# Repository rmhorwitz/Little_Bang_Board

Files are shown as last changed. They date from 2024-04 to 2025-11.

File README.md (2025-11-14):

# Little_Bang_Board
This project is for a Virtual Pinball game controller based on a Rasberry Pi Pico called thew Little Bang Board.  The Little Bang Board is the Open Source DIY version of the Baby Bang Board which uses SMT and JST connectors, it is intented for commercial use by Intense Arcade.  The Little Bang Board provides a virtual ball plunger using the game controller Z axis of a joystick output.  An accelerometer provides X/Y movement to the applicable game controller X/Y joystick output. A true USB keyboard HID emulation provides 16 buttons that can emulate any key.  Basic pinball game controllers can cost anywhere from $40 to $125. The Little Bang Board will set you back $10 and will be as good if not better than the more expensive competition. This project can also be purchased as a complete kit for under $20.  The project is offered as is, and free to copy and use.  If used for profit, all I ask is that the project name not be changed.  
Items in this project that I am providing include Instructions, BOM, PCB fab files (gerbers and drill files) links to Adafruit CircuitPython for Pico, links to Adafruit CircuitPython libraries, schematics, config.txt, Code.py -Main Code, and Boot.py -boot code.  Alternately, I am including a sample script for using Pinscape Pico which is the preferred software for this project. For information and code download concerning MJR's Pinscape for Pico please follow his GitHub page at https://github.com/mjrgh/PinscapePico.  Please enjoy this project. 
Little Bang Board Version 2 has been released.  This new design has the following changes:

JST input/button connector have been replaced with two, ten pin standard terminal blocks

Two additional Inputs for a total of 18

All inputs are pulled high for use of a common ground

Support for AD1115 ADC Module.  This makes this project in-line with MJR's Pinscape Pico project

Support for either LIS3DH or MMA485X Accelerometers, circuit supports interupts for both modules

Expansion port was modified to support MJR's Pinscape Pico DIY Power Board

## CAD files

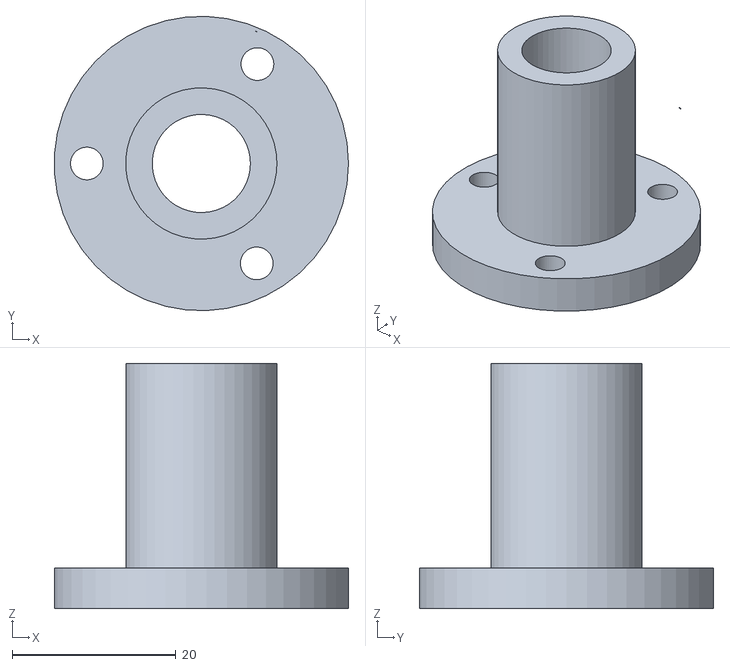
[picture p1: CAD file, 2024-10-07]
Shooter flange.stl
36.0 x 36.0 x 30.0

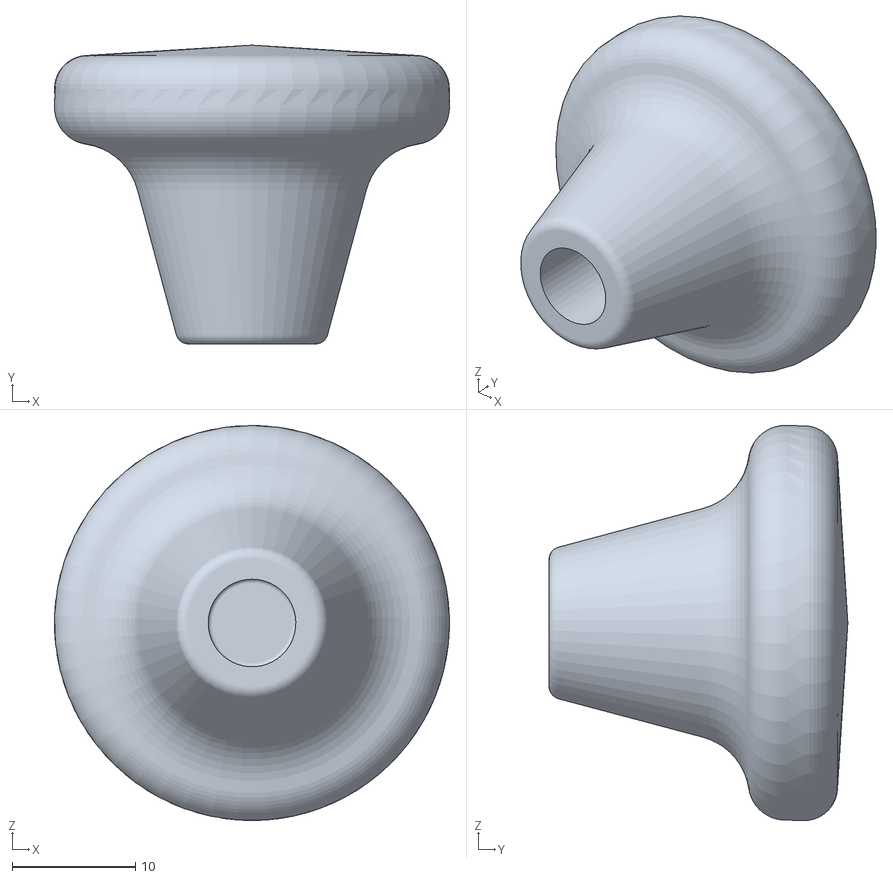
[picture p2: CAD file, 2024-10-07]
shooter_knob_r3.stl
32.0 x 24.2 x 32.0

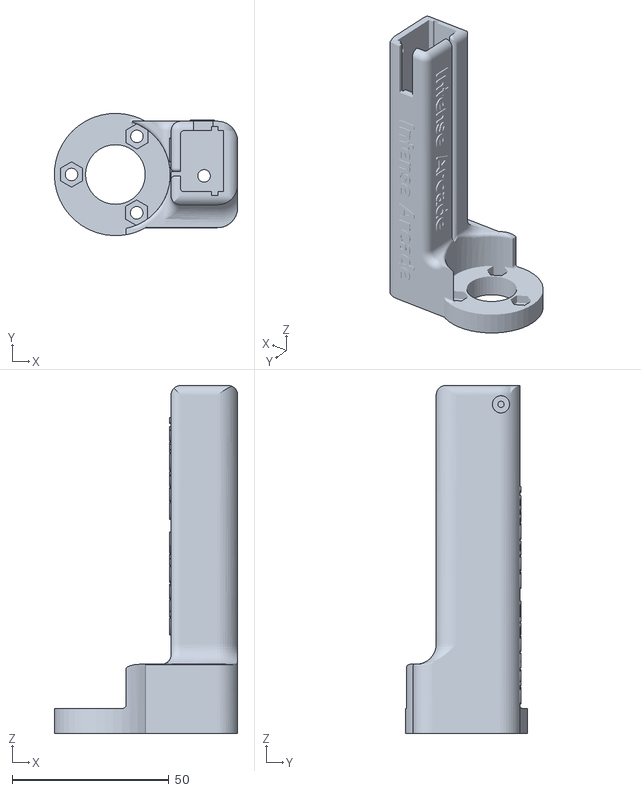
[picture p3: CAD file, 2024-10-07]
shooter62.stl
58.5 x 39.0 x 111.0

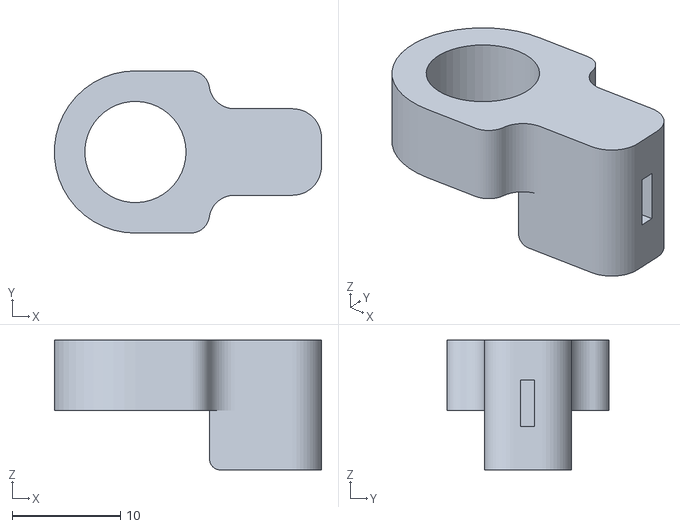
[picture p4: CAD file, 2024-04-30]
shooter_retainer_rev_4.stl
24.7 x 15.0 x 12.0

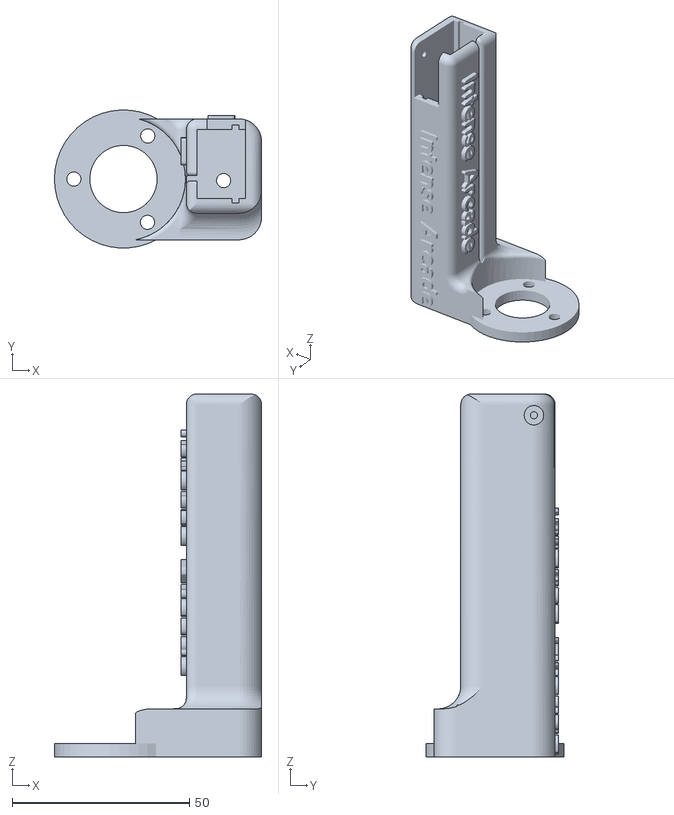
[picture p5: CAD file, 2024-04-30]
shooter58.stl
58.5 x 38.9 x 102.5

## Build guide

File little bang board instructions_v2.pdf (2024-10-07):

# Little Bang OS Virtual Pinball Controller

Version 2.00
Author: Rickey M. Horwitz

## Introduction

This document details the assembly of a game controller specifically used to interface with a virtual pinball machine. The document provides detailed instructions on theory of operation, assembly, test, and implementation.

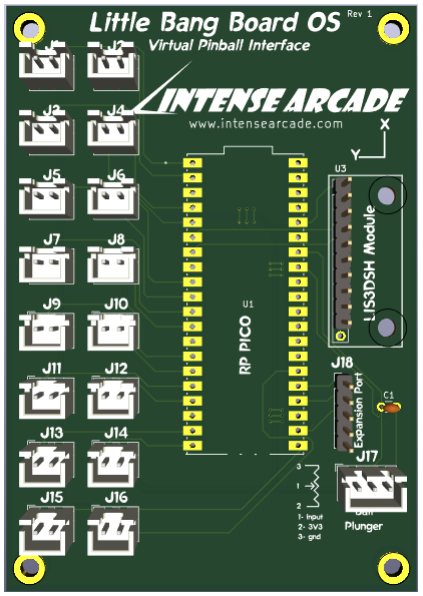
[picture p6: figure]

## Description

This project revolves around a Raspberry Pi Pico module. The Raspberry Pi Pico is a system on a chip contain a dual core ARM Cortex 11 processor that provides a peripheral interface between the human and host PC using USB, like a keyboard, mouse, or joystick. These are commonly referred to as USB HID devices. Devices such as mechanical buttons, accelerometer, and a ball plunger are connected to the Pico via Printed Circuit Board (PCB). The signals from these devices are processed in the Pico and sent to the host PC using a Joystick and Keyboard HID interface to ultimately control a virtual pinball application.

Specifications

- Interface: | USB 1.1
- USB HID Types: | Joystick/Gamepad and Keyboard on a single USB
- Button inputs: | 16 each, debounced at .03 seconds (30 milliseconds).
- Button latency: | .003 seconds (3 milliseconds)
- Ball Plunger: | 16-bit, sampled at 333 Hz (.003 seconds)
- Accelerometer: | LIS3DSH, 10-bit, X/Y axis sampled at 100 Hz (.01 seconds)

## Project Summary

The Little Bang Board OS is a DIY kit that comes complete with all components except button cables. The following will be in the kit:

1. Little Bang PCB | qty 1
2. LIS3DSH Module | qty 1
3. RP Pico Module | qty 1
4. JST XH 2 pin header | qty 16
5. JST XH3 Pin header | qty 1
6. 11 pin header | qty 1
7. 20 pin header | qty 2
8. 5 pin header | qty 1
9. .1ufd Capacitor | qty 1
10. USB A to C, 1m | qty 1

The project requires soldering components to a PCB. A soldering iron and rosin core solder are required. Assembling this project should not take longer than a half hour to complete. The Raspberry Pi Pico is the most powerful and versatile hobby processor on the market today. The extremely low cost makes it an ideal choice for almost any project. The LIS3DSH accelerometer module was chosen as it is the most popular model available, and the performance is very good. The PCB design uses JST XH 2.5mm pitch connector for all inputs. This allows either JST XH or Dupont connector terminated cables making the design neat and clean.

## Instructions

- Locate both 20-pin, single-row headers for the Pico and install these headers into the PCB (but not soldered).
- Place the Pico module on top of the pin headers. Orient the Pico so that the USB port faces towards the top of the PCB.
- Once the pin headers are fully aligned with the holes on both module and PCB, the pins are ready to be soldered. Try soldering the four corners first so that adjustments can be made without damaging the assembly.

- For the LIS3DSH module, install the pin header first, ensure that the pins are aligned squarely with the PCB before soldering them.
- When soldering the LIS3DSH module to the pin header it is important that both module and PCB are parallel. Failure to do so will result in nudging errors and the virtual playfield not being level with the cabinet.
- Solder all the JST 2-pin header connectors (J1-J16). It is best to solder a single pin on each of these connectors so that that can all be aligned correctly before soldering.
- Solder header connector J17 and J18.
- C1 is a .1ufd ceramic capacitor used for filtering the Plunger input. Add this component if not using an Intense Arcade Plunger/Ball Shooter assy.
- Inspect the bottom of your PCBA for any solder bridging. Any bridging may roach your board.
- A USB C to standard A cable is required. This design uses the older USB 1.1 specification and as such the cable length can be 2 meters long without any issues.
Note
The RP Pico comes pre-programmed with a default configuration script installed.
- On your PC, bring up Device Manager and look for an extra HID Compliant Consumer Control Device, HID Compliant Game Controller, and a USB Input Device.

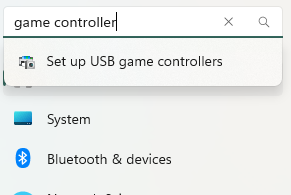
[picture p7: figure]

- In Windows settings, select ‘Set up USB game controllers’:
- A list should appear in a window that looks like:

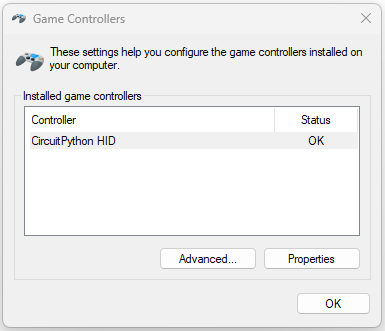
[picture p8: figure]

- Select the CircuitPython HID and click on ‘Properties’

- The following window should appear:

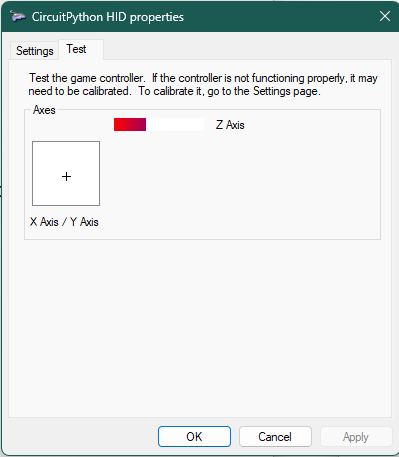
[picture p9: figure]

- Shake the Little Bang Board and ensure that the X/Y axis moves accordingly.
- Pull the ball Plunger back and forth and ensure that the Z axis reacts accordingly.
- Click on OK and close the CircuitPython HID properties.
- Open the notepad app on the PC, in the session press the buttons on the Little Bang Controller that correspond to the keystrokes on the keyboard. Ensure that they all work accordingly. Installing the little bang board assembly
Mounting the assembly should follow these requirements:
- The assembly should be mounted within reach of the button wires, plunger wires, and USB cable
- The USB plug requires at least 40 mm length allowance for strain relief.
- The mounting area needs to be flat and level.
- Route plunger wires away from other wires. This will reduce electrical noise and reduce plunger jitter.
- After mounting, check the level by running the windows game controller utility.
- If the X/Y accelerometer is picking up too much vibration from the cabinet during no activity, the dead band may need to be increased. This can be accomplished by modifying the configuration script.
Configuration Editing
As mentioned, the Bang Board uses a texted based configuration file that is located on the RP Pico.
When the board’s USB is plugged into a PC, it will appear as a flash drive. You can browse the files on this drive and find the ‘config.txt’ file. At the time of this publication, this file needs to be edited manually and only the first 24 lines of this file are relevant. So, let’s explore them.
Note
Do not delete the configuration file!!

Accelerometer Dead Band
Noise and vibration will cause the accelerometer to fluctuate, showing up as a jitter. Increasing the dead band value reduces this affect. Placing the value to too high will make the accelerometer unresponsive to slight nudging. Set this value to 500-1000.
X_ Accelerometer Gain and Y_ Accelerometer Gain
If nudging is not producing the correct response, try adjusting this value. By default, both X and Y are set to 3500.
Accelerometer Orientation
When mounting the Bang Board in your Pinball cabinet, be mindful of the orientation of the mounting of the PCBA. The PCBA has an in indicator showing the X and Y orientation”. Orientation assumes a right-angle placement. So, there is 0, 90, 180, and 270 degrees which are enumerated as 0, 1, 2, and 3 respectively.
Plunger Offset
This value is not yet implemented in this software and doubtfully will it ever be. The offset is the value that

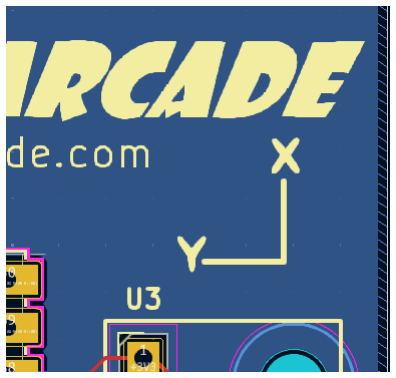
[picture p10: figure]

Plunger Gain
A virtual pinball plunger uses a linear potentiometer that has an output voltage directly proportional to the position of the wiper. Some virtual pinball plunger implementations lack full range from their slider potentiometer. In the case of the Bang Board, the voltage range of this pot is 0 to 3.3V which is the full extent with an Intense Arcade Plunger. The Plunger gain is a value that modifies the output to compensate for limitations. If you use an Intense Arcade shooter leave this value at default.

Button Values
As stated, the Little Bang Board supports up to 16 button inputs. These buttons correspond to any keystroke on a keyboard. The names of each keystroke use the naming conventions in Python. Below is an excerpt of an actual configuration script.
acc_deadband = 1000
x_acc_gain = 3500
y_acc_gain = -3500
acc_orientation = 1
plunger_offset = 1
plunger_gain = 1
button_01 = LEFT_SHIFT
button_02 = RIGHT_SHIFT
button_03 = LEFT_CONTROL
button_04 = RIGHT_CONTROL
button_05 = ONE
button_06 = FIVE
button_07 = FOUR
button_08 = ENTER
button_09 = Q
button_10 = EQUALS

button_11 = MINUS
button_12 = F11
button_13 = T
button_14 = SPACE
button_15 = FOUR
button_16 = ENTER

Saving The Configuration
Sometimes the Pico may prevent you from saving the configuration on the device. In cases where this occurs simply press the RST key on the Pico module and wait for the flash drive to reappear and proceed to save the file.
RP Pico Variants
The RP Pico comes in two variants for this project, each having a USB C interface and each functioning identically. The first variant is non castellated through hole mounted and includes an onboard Neo Pixel (RGB) LED. The control for this LED is GP23 (pin 37). To add an external Neo Pixel (WS2812B), remove the RGB solder jumper and tap pins 37 (GP23), 40 (5V) and 38 (GND).
The alternate variant sticks to the RP Pico module standard. It is suggested to not attempt to solder it directly to the PCB, as the USB cable my have issues with clearance. This variant does not have the Neo Pixel GP23.
Expansion Port
The expansion port is designed for adding PWM controlled output driver board using a SPI port and 3.3V. 1- GP20
2 - GP18
3 - GP19
4 - 3.3V
5 - GND

Contact Me
This is an open-source project I created and can be accessed on GitHub at https://github.com/rmhorwitz/Little_Bang_Board/
If you have any questions, contact me at rick.horwitz@yahoo.com
I also have a website www.IntenseArcade.com where I sell small VP cabinets and affordable parts.

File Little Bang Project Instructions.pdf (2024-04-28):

# LITTLE BANG VIRTUAL PINBALL CONTROLLER

Version 1.00, first hack

Author: Rickey M. Horwitz

INTRODUCTION

This document details the design and assembly of a game controller specifically used to interface with a virtual pinball machine. The document provides detailed instructions on theory of operation, logistics, assembly, test, and implementation.

DESCRIPTION

This project revolves around a Raspberry Pi Pico module. The Raspberry Pi Pico is a system on a chip that provides a peripheral interface between the human and host PC using USB, like a keyboard, mouse, or joystick. These are commonly referred to as USB HID devices. Devices such as mechanical buttons, accelerometer, and a ball plunger are connected to the Pico and the signals from these devices are processed in the Pico and sent to the host PC using a Joystick and Keyboard HID interface to ultimately control a virtual pinball application.

SPECIFICATIONS

- | Interface: | USB 1.1
- | USB HID Types: | Joystick/Gamepad and Keyboard on a single USB
- | Button inputs: | 16 each, debounced at .03 seconds (30 milliseconds).
- | Button latency: | .005 seconds (5 milliseconds)
- | Ball Plunger: | 16-bit, sampled at 200 Hz (.005 seconds)
- | Accelerometer: | LIS3DH, 10-bit, X/Y axis sampled at 100 Hz (.01 seconds)

PROJECT SUMMARY

The project requires only a few components and shouldn’t take long to assemble. The Raspberry Pi Pico is the most powerful and versatile hobby processor on the market today. The extremely low cost makes it an ideal choice for almost any project. The LIS3DH accelerometer module was chosen as it is the most popular model available and should be available for at least 10 years.

The RP Pico module is interfaced to a LIS3DH module by four wires: 3.3V, GND, SDL-I2C, SDA-I2C. Up to 16 buttons are soldered to I/O pins to the Pico. The other ends to the buttons are all tied to 3.3V supplied by pin 36 on the Pico module. A linear potentiometer (for ball plunger) is wired to the Pico module using the 3.3V, GND, and ADC2 (pin 34).

INSTRUCTIONS

Follow the instructions in the following sections.

BILL OF MATERIALS

HARDWARE

- Raspberry PI Pico development board https://www.adafruit.com/pico?src=raspberrypi

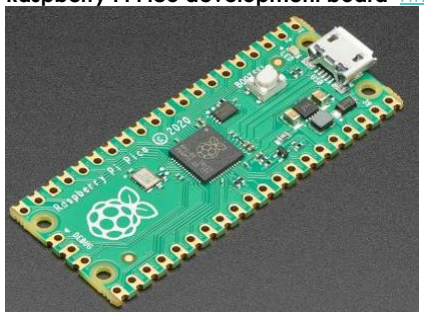
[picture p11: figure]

- LIS3DH https://www.adafruit.com/product/2809

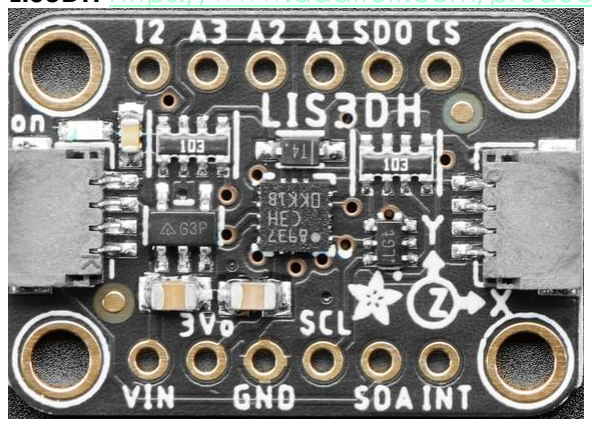
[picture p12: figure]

- 24 AWG Zip wire https://www.amazon.com/American-Stranded-Power-Speaker-Available/dp/B0791C68HJ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 nzHX4_aHcZd-bF5yzhOngNmp3rqQQBmCJAGkc.AjGd9jBQ-r1Yd_lDxv68nj3t93yKsz_N-WcXdJ_uX8U&dib_tag=se&keywords=24%2BAWG%2Bzip%2Bwire&qid=1714151230&sprefix=24%2Bawg%2Bzi p%2Bwire%2Caps%2C78&sr=8-1&th=1 (https://www.amazon.com/American-Stranded-Power-Speaker-Available/dp/B0791C68HJ)
- USB Micro to USB A

OPTIONAL HARDWARE

This hardware is beyond the scope of this document but a useful reference for needed items to complete a pinball cabinet.

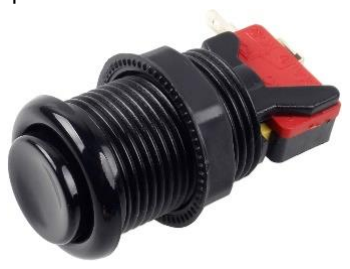
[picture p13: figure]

Arcade Buttons - https://www.diyretroarcade.com/products/american-style-28mmstandard-arcade-push-button-for-arcade1up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 (https://www.diyretroarcade.com/products/american-style-28mm-standard-arcade-push-button-for-arcade1up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)

### Ball Plunger - Complete system includes linear potentiometer, plunger mechanism, Beehive bezel, feruled wiring, and binding post. This assembly is

provided by Intense Arcade which authored this project.

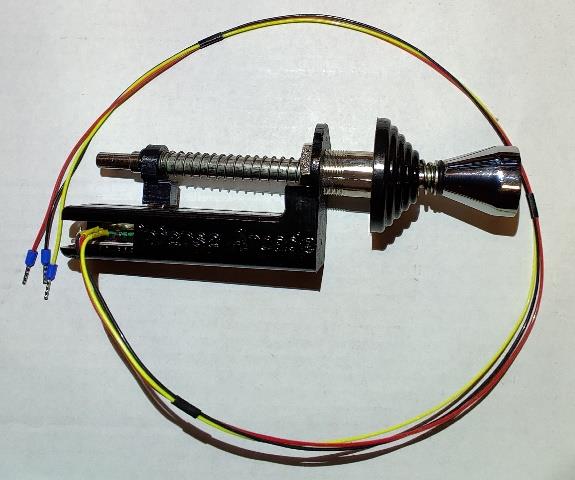
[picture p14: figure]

LIS3DH module generic https://www.amazon.com/HiLetgo-Tri-Axis-Acceleration-Development-TemperatureSensor/dp/B082W63MWL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 (https://www.amazon.com/HiLetgo-Tri-Axis-Acceleration-Development-TemperatureSensor/dp/B082W63MWL)

This is an alternative to the Adafruit module. I used these on my prototype, and they worked fabulously. This generic version does not have a built-in 3.3V LDO and as such relies on the Pico’s built in 3.3V regulator.

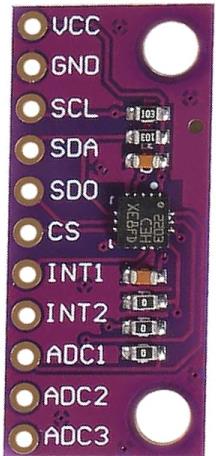
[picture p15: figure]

Project Bread Board
https://www.amazon.com/gp/product/B00FXHXT80/ref=ppx_yo_dt_b_search_asin_title?ie=UTF8&psc=1

SOFTWARE

CircuitPython 9.X - https://circuitpython.org/board/raspberry_pi_pico/

CircuitPython Library bundle 9.X https://circuitpython.org/libraries

Joystick_XL https://github.com/fasteddy516/CircuitPython_JoystickXL

Little Bang Pico boot file -in this github

Little Bang Pico code file -in this github

REFERENCE DOCUMENTATION

RP Pico description https://www.raspberrypi.com/documentation/microcontrollers/raspberry-pi-pico.html

LIS3DH data sheet https://www.st.com/resource/en/datasheet/lis3dhh.pdf

Joystick_XL documents https://circuitpython-joystickxl.readthedocs.io/en/latest/

HARDWARE ASSEMBLY

The hardware assembly is presented in three illustrations: accelerometer, buttons, and ball plunger potentiometer. All three of these devices need to be wired and installed as shown. Common to all three device interfaces is Pico pin 36, 3.3V (If using the generic LIS3DH). Ensure that accommodation is made to accept three connections to this single pin. As shown in the RP Pico figure below, there are several ground pins (GND). The ground pin for the Ball Plunger is exclusive to the ground on pin 33. NO OTHER DEVICES SHOULD USE THIS GROUND!!

The Illustration below shows an overview of the RP Pico.

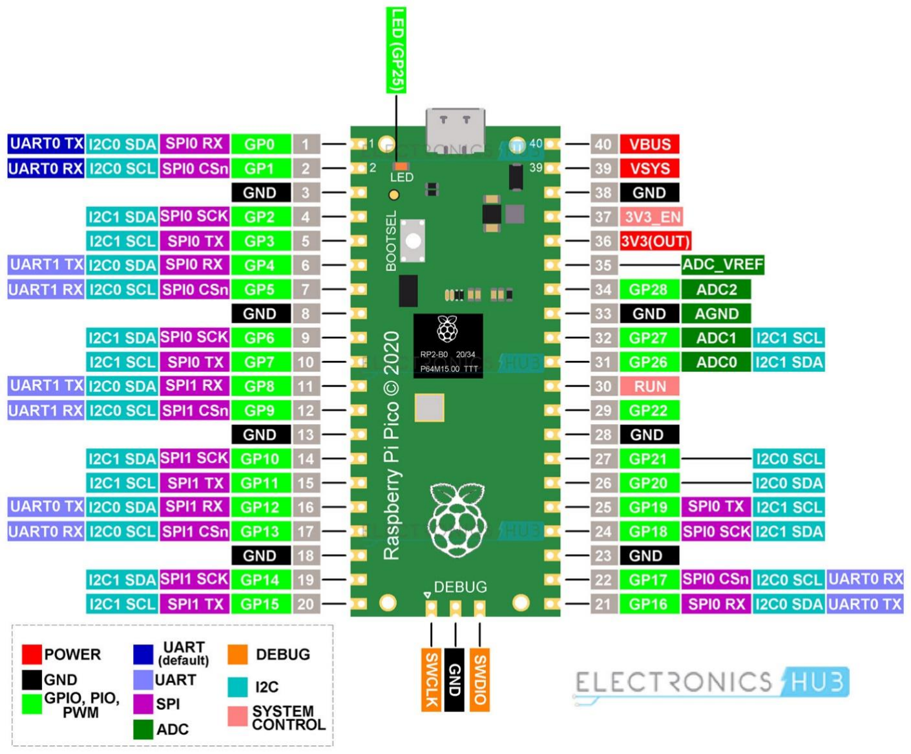
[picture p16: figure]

LIS3DH INTERFACE TO THE PICO

This illustration highlights the LIS3DH to Pico Interface. The ball plunger and buttons are omitted for clarity. The accelerometer must be mounted close to the SCL/SDA pins to ensure data integrity. The wire length should not exceed 75 mm for these two data lines. The LIS3DH module shown in this example is a generic module and is physically different than an Adafruit. This module needs to be securely mounted flat and level inside the pinball cabinet. The Y axis should run forward and aft of the cabinet, while the Y axis runs left and right. Again, this module must be level in both axis to work properly.

The example shown here uses a generic LIS3DH module that does not have a built-in LDO 3.3V supply. As such, it gets its power from the Pico’s built-in 3.3V. If using the Adafruit module, use the Vin for supplying the needed 5V from the Pico’s VBUS on pin 40.

CAUTION

DO NOT FEED VBUS (PIN 40 FROM PICO) TO THE 3Vo PIN. IT WILL DESTROY THE MODULE

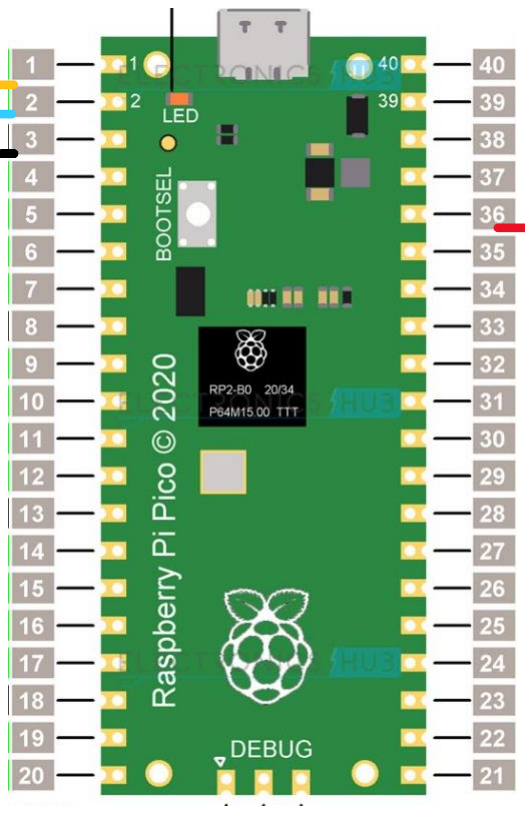
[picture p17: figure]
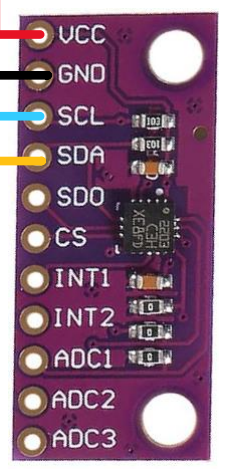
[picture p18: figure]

If the axis appears to operate backwards, a python code modification will be needed. Removing or adding a (-) to the 3500 gain factor will change the axis direction.

x_acc.value = int((lis3dh.acceleration.x) * -3500)

y_acc.value = int((lis3dh.acceleration.y) * 3500)

3.3V

BUTTON INTERFACE TO THE PICO MODULE

This illustration highlights the connections for the buttons on the Pico. LIS3DH and ball plunger have been omitted for clarity. The GP I/O outputs are pulled low and use the Pico’s onboard 3.3V supply to switch the I/Os high. Refer to table 1 that shows the GP I/O to the designated keys.

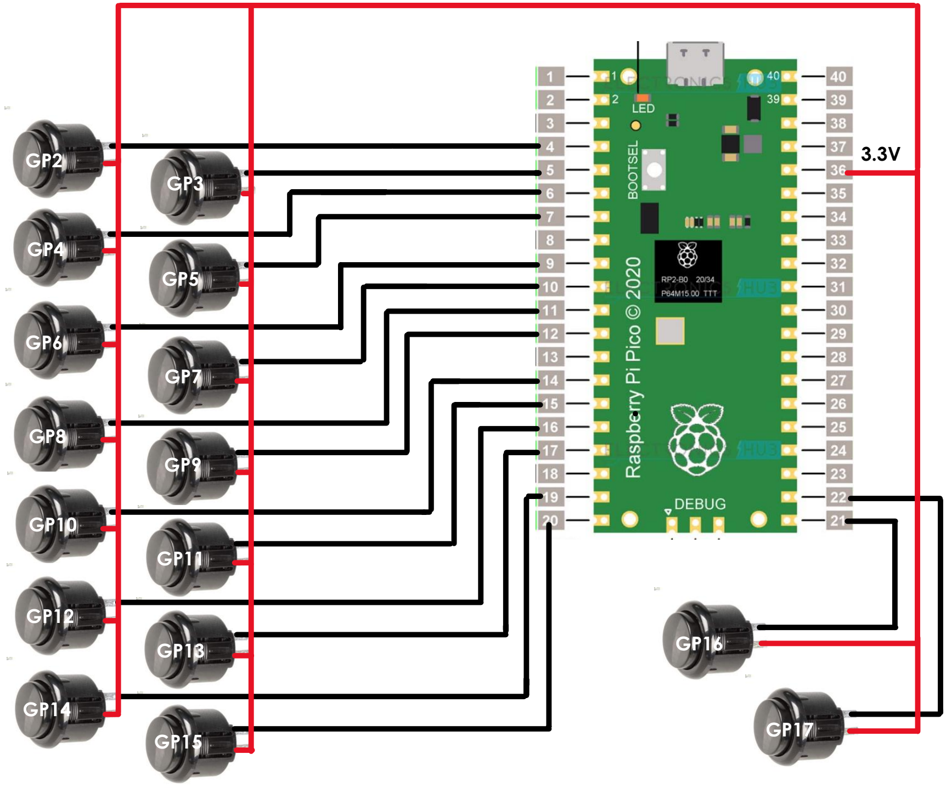
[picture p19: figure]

TABLE 1

GP I/O Pin | BTN # | Keystroke
GP2 | Button_1 | Left Shift
GP3 | Button_2 | Right Shift
GP4 | Button_3 | Left Control
GP5 | Button_4 | Right Control
GP6 | Button_5 | 1
GP7 | Button_6 | 5
GP8 | Button_7 | 4
GP9 | Button_8 | Enter
GP10 | Button_9 | q
GP11 | Button_10 | =
GP12 | Button_11 | -
GP13 | Button_12 | F11
GP14 | Button_13 | t
GP15 | Button_14 | 5
GP16 | Button_15 | 4
GP17 | Button_16 | Enter

The designated keys above can be changed in the python code.

BALL PLUNGER INTERFACE TO THE PICO

This illustration highlights the connections for the ball plunger to the Pico. LIS3SH and buttons have been omitted for clarity. The ball plunger uses a linear potentiometer (pot) to measure the movement of the ball plunger. As the plunger moves, the pot’s wiper changes resistance which is measured as volts to ADC 02 on the Pico. The Pico’s 3.3V onboard supply (pin 36) is used to power the pot, while the pot return is attached to AGND (pin 33). The value of this pot must be in the range of 5k to 20k ohms and cannot use an audio or logarithmic taper.

The length of the wires for the ball plunger depends on the value of the pot, how the wires are routed, and how much electrical noise is in the cabinet. Noise will cause the plunger to jitter. 500mm is the nominal length using a 20k ohm pot. 1 meter length is okay for a 5 to10k pot. If noise is persistent in your cabinet, try using shielded wire. Ensure only to ground one end of the shield to any ground on the Pico provided it’s not pin 33.

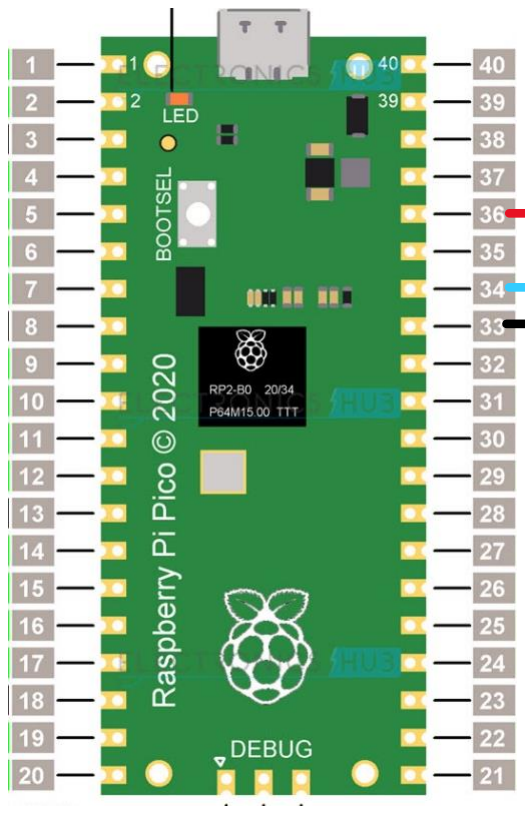
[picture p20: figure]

3.3V

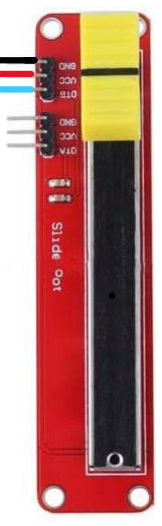
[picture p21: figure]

Wiper
GND

SOFTWARE CONFIGURATION

The Little Bang Board uses CircuitPython programming language to tell it what to do. Assuming that all the software outlined in this instruction has been downloaded and all devices have been wired as detailed, follow the steps below:

- Attach a micro USB cable between a host computer and the RP Pico.
- The RP Pico should show up as a drive with a volume named RPI RP2 on the PC. See below:

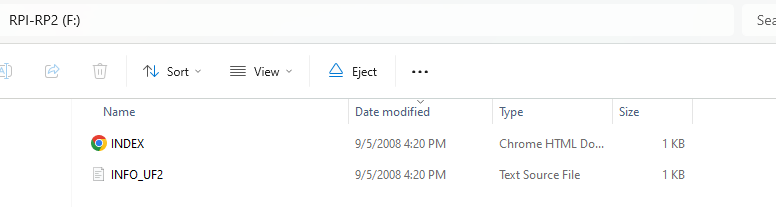
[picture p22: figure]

- Locate the latest release version of CircuitPython and copy it to the root drive of the RP Pico.

Note

This project was tested using CircuitPython version 9.x with 9.x libraries

- Once the file is copied, the RP Pico will reboot and when it returns, the volume name will change to CIRCUITPY, and the drive should look like this:

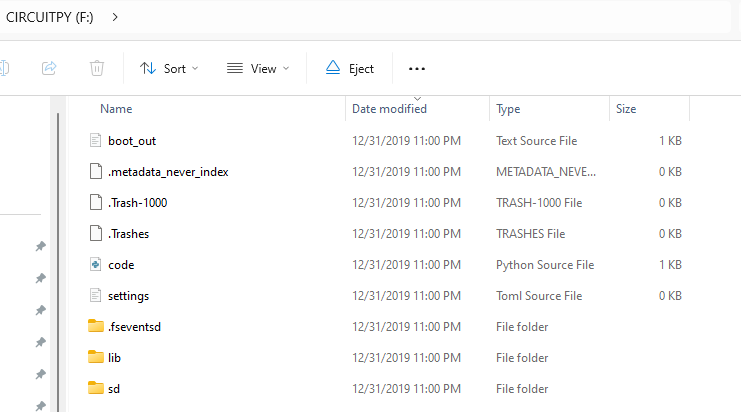
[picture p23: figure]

- Assuming that the Adafruit libraries and Joystick_XL library are both present, copy the following folders/files and place them directly into the \lib folder on the RP Pico. It should look like this:

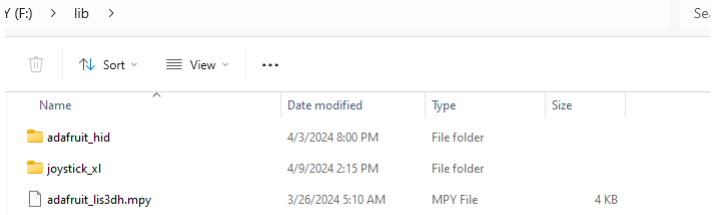
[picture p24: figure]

- Take both the boot.py and code.py files found on Github and copy them to the root of the RP Pico. Your root folder on the RP Pico should look like this.

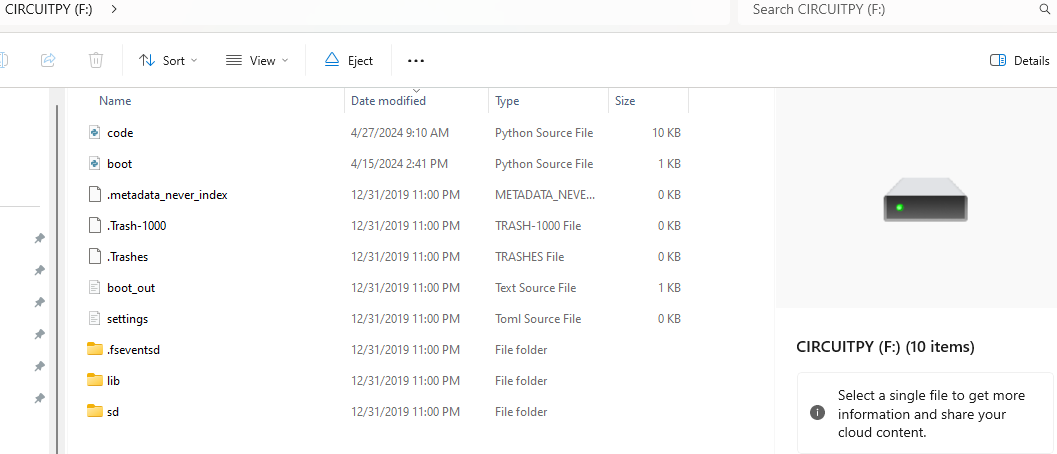
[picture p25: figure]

- On your PC, bring up Device Manager and look for an extra HID Compliant Consumer Control Device, HID Compliant Game Controller, and a USB Input Device.
- In Windows settings, select ‘Set up USB game controllers’:

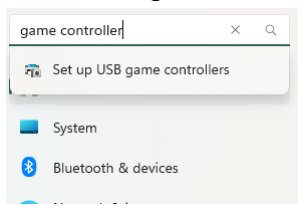
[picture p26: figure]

- A list should appear in a window that looks like:


- Select the CircuitPython HID and click on ‘Properties’
- The following window should appear:


- Shake the Little Bang Controller and ensure that the X/Y axis moves accordingly.
- Pull the ball Plunger back and forth and ensure that the Z axis reacts accordingly.
- Click on OK and close the CircuitPython HID properties.
- Open the notepad app on the PC, in the session press the buttons on the Little Bang Controller that correspond to the keystrokes on the keyboard. Ensure that they all work accordingly.

INSTALLING THE LITTLE BANG BOARD ASSEMBLY

Mounting the assembly should follow these requirements:

- The assembly should be mounted within reach of the button wires, plunger wires, and USB cable
- The USB plug requires at least 40 mm length allowance.
- The mounting area needs to be flat and level.
- The Accelerometer Y-axis should run forward and aft while the X-axis runs left and right.
- Route plunger wires away from other wires. This will reduce electrical noise and reduce plunger jitter.
- After mounting, check the level by running the windows game controller utility.
- If the X/Y accelerometer is picking up too much vibration from the cabinet during no activity, the dead band may need to be increased. This can be accomplished using a text editor or Mu by modifying the following lines of code shown below:

js.add_input(

Axis(x_acc, 1000, -32000, 32000), # the first arg is the dead band, this keeps the table from shaking.

Axis(y_acc, 1000, -32000, 32000), #2nd is the lowest int, and the 3rd is the highest int

Axis(Plunger),

Increase the yellow highlighted numbers. Be careful not to raise these numbers too high, as this may cause the program to crash.

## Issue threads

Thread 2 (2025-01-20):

Button inputs hi/low

jueank, 2025-01-20:
Hi!
I just discovered your project and I think it's great! It's a pity that the Pinscape boards are slowly moving out of the focus of pinball users because the KL25Z are so poorly available (at least in Europe). So, great that you started the project!
I have a question about the button inputs: They are pulled low by default and set to 3.3V when being pushed. This is different from what Pinscape does, where they are held high and pulled to ground.
Is there a technical reason for doing it like this? I'm asking because I have broken my KL25Z - that's the reason why I'm trying your design now, but all my buttons are already wired. So I would have to re-wire them. I understand that this is a purely personal thing. Besides that, I see reasons, why doing it the way Pinscape does has benefits:
- You don't have to run an extra wire for 3.3V to the buttons. GND is available there most of the time anyway (e.g. when using illuminated buttons) or at least close by.
- It's more of a plug and play alternative to Pinscape, since it follows the same wiring principle.

In case you don't want to change this completely, could you imagine making it configurable in software, whether the inputs are held low or high by default and tested against being pulled up or down?
(Edit: I know that the JST header are currently hardwired to 3.3V)

rmhorwitz, 2025-04-07:
Jueank,
Thank you for pointing this out.  I had the same suggestion from Mike Roberts and as such, I have changed my schematic to reflect this suggestion.

Closed 2025-04-07.

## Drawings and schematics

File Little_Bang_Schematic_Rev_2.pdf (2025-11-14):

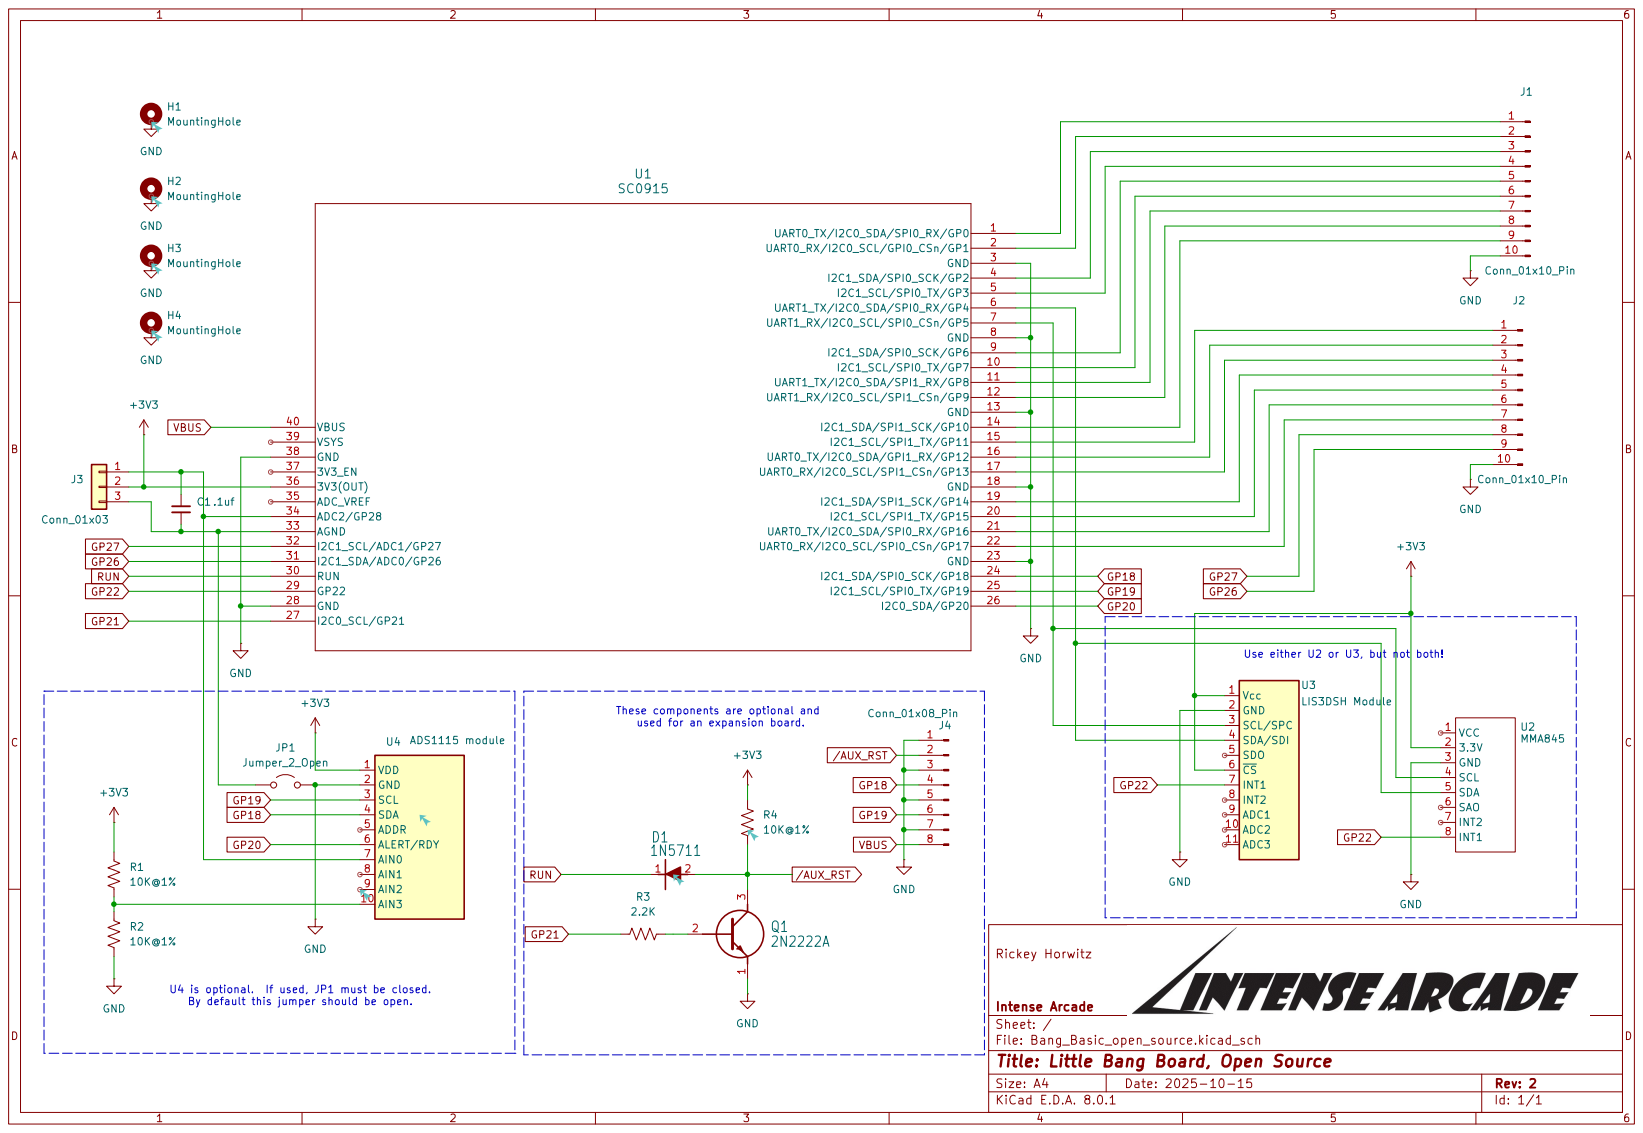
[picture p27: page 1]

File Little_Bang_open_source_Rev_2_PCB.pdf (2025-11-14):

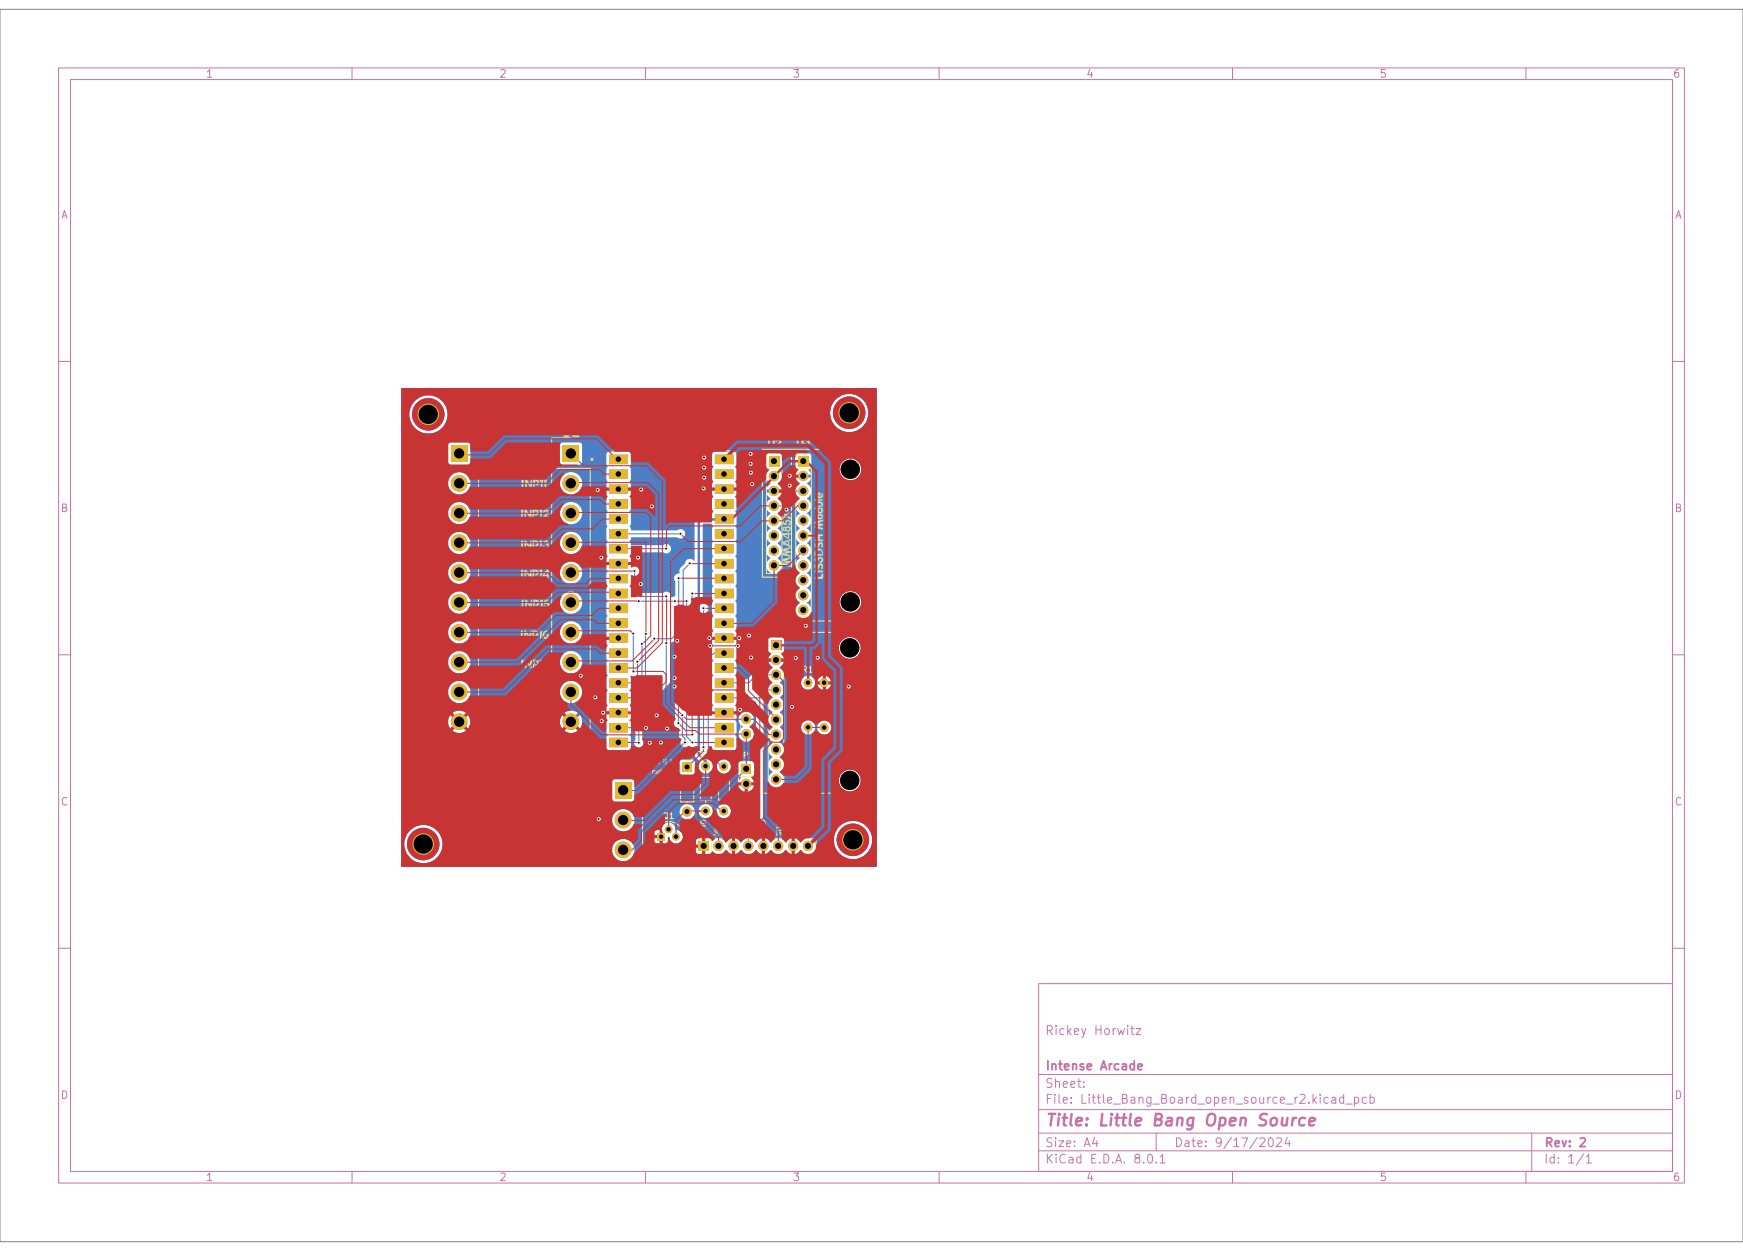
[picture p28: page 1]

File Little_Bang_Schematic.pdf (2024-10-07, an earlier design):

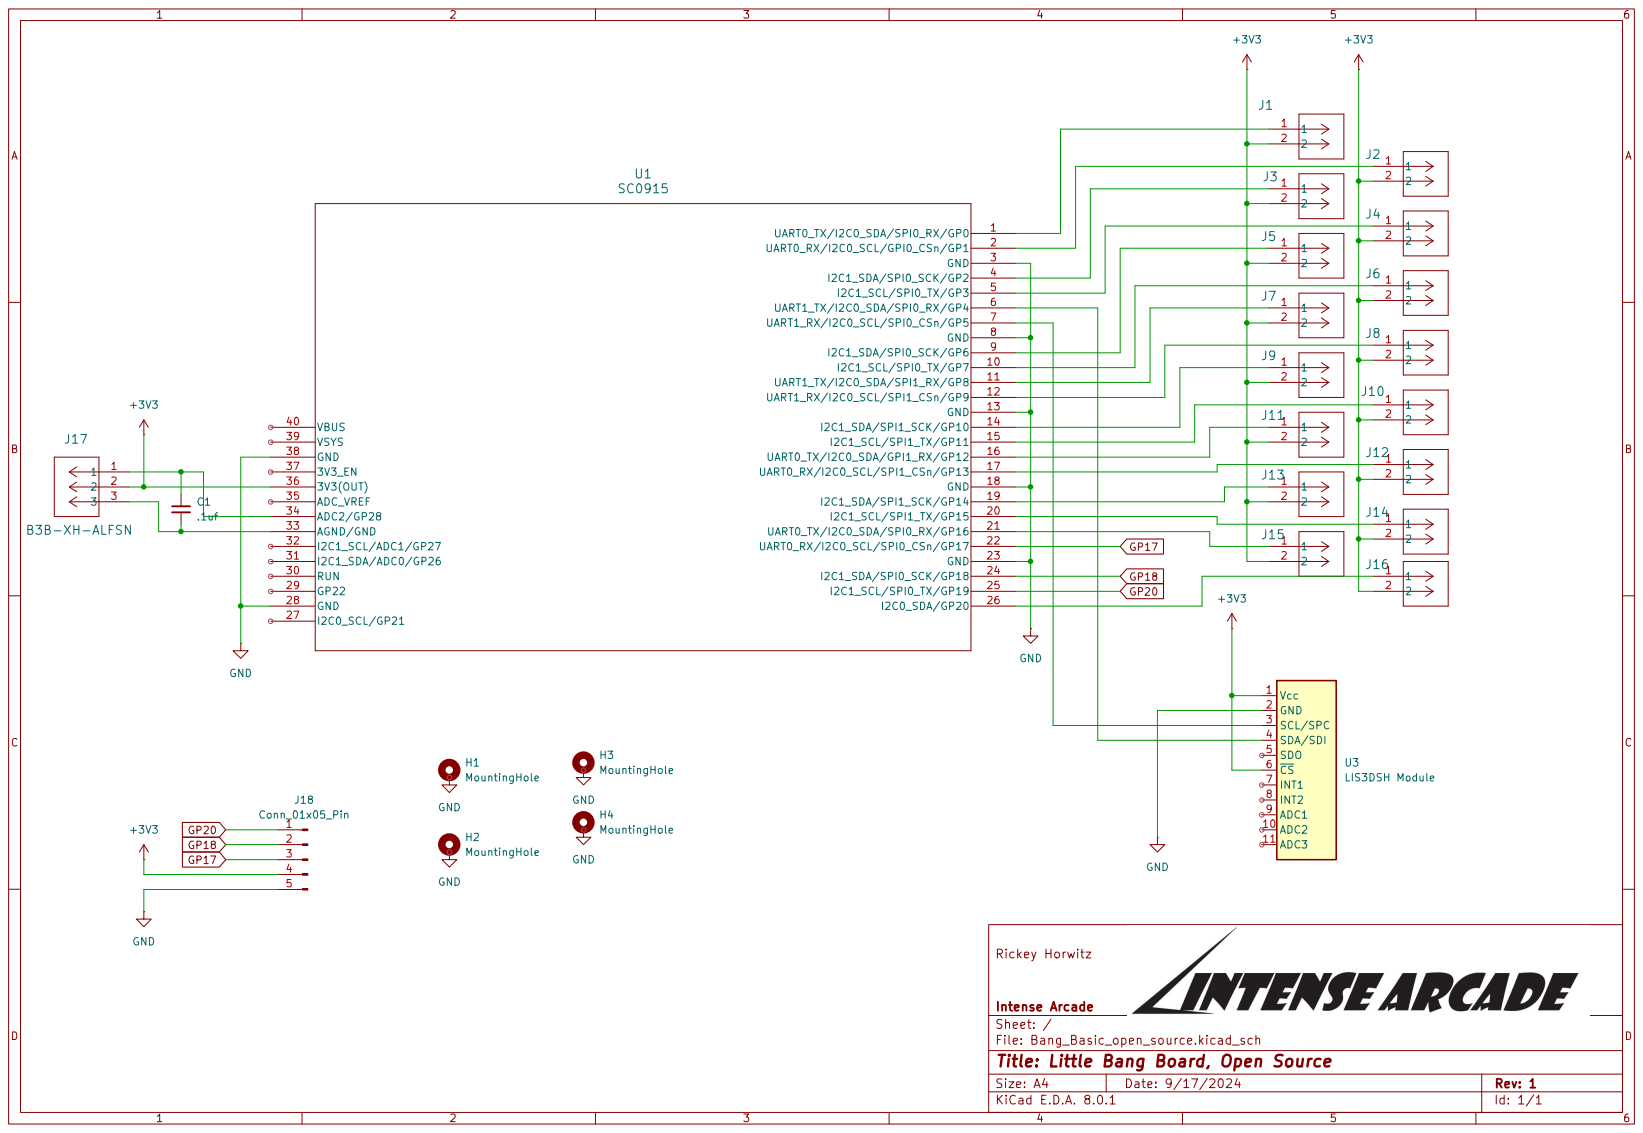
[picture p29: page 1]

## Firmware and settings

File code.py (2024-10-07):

"""code.py"""
"""Created by Rickey M Horwitz, Intense Arcade"""
import time
import board
import busio
import digitalio
import adafruit_lis3dh
import adafruit_tlc5947
import analogio
import usb_hid
from joystick_xl.inputs import Axis
from joystick_xl.joystick import Joystick
from adafruit_hid.keyboard import Keyboard
from adafruit_hid.keyboard_layout_us import KeyboardLayoutUS
from adafruit_hid.keycode import Keycode

configdata = open("config.txt", "r")

row = configdata.readlines()
for line in row:
    if line.find("acc_deadband") > -1:
        info = line.split()
        acd = int(info[2])
    if line.find("x_acc_gain") > -1:
        info = line.split()
        xag = int(info[2])
    if line.find("y_acc_gain") > -1:
        info = line.split()
        yag = int(info[2])
    if line.find("acc_orientation") > -1:
        info = line.split()
        ao = int(info[2])
    if line.find("plunger_offset") > -1:
        info = line.split()
        po = int(info[2])
    if line.find("plunger_gain") > -1:
        info = line.split()
        pg = int(info[2])
    if line.find("button_01") > -1:
        info = line.split()
        btn_1 = info[2]
    if line.find("button_02") > -1:
        info = line.split()
        btn_2 = info[2]
    if line.find("button_03") > -1:
        info = line.split()
        btn_3 = info[2]
    if line.find("button_04") > -1:
        info = line.split()
        btn_4 = info[2]
    if line.find("button_05") > -1:
        info = line.split()
        btn_5 = info[2]
    if line.find("button_06") > -1:
        info = line.split()
        btn_6 = info[2]
    if line.find("button_07") > -1:
        info = line.split()
        btn_7 = info[2]
    if line.find("button_08") > -1:
        info = line.split()
        btn_8 = info[2]
    if line.find("button_09") > -1:
        info = line.split()
        btn_9 = info[2]
    if line.find("button_10") > -1:
        info = line.split()
        btn_10 = info[2]
    if line.find("button_11") > -1:
        info = line.split()
        btn_11 = info[2]
    if line.find("button_12") > -1:
        info = line.split()
        btn_12 = info[2]
    if line.find("button_13") > -1:
        info = line.split()
        btn_13 = info[2]
    if line.find("button_14") > -1:
        info = line.split()
        btn_14 = info[2]
    if line.find("button_15") > -1:
        info = line.split()
        btn_15 = info[2]
    if line.find("button_16") > -1:
        info = line.split()
        btn_16 = info[2]
    if line.find("outp_01") > -1:
        info = line.split()
        outp_1 = tuple(
            (int(info[2]), int(info[4]), int(info[6]), int(info[8]), int(info[10]))
        )
    if line.find("outp_02") > -1:
        info = line.split()
        outp_2 = tuple(
            (int(info[2]), int(info[4]), int(info[6]), int(info[8]), int(info[10]))
        )
    if line.find("outp_03") > -1:
        info = line.split()
        outp_3 = tuple(
            (int(info[2]), int(info[4]), int(info[6]), int(info[8]), int(info[10]))
        )
    if line.find("outp_04") > -1:
        info = line.split()
        outp_4 = tuple(
            (int(info[2]), int(info[4]), int(info[6]), int(info[8]), int(info[10]))
        )
    if line.find("outp_05") > -1:
        info = line.split()
        outp_5 = tuple(
            (int(info[2]), int(info[4]), int(info[6]), int(info[8]), int(info[10]))
        )
    if line.find("outp_06") > -1:
        info = line.split()
        outp_6 = tuple(
            (int(info[2]), int(info[4]), int(info[6]), int(info[8]), int(info[10]))
        )
    if line.find("outp_07") > -1:
        info = line.split()
        outp_7 = tuple(
            (int(info[2]), int(info[4]), int(info[6]), int(info[8]), int(info[10]))
        )
    if line.find("outp_08") > -1:
        info = line.split()
        outp_8 = tuple(
            (int(info[2]), int(info[4]), int(info[6]), int(info[8]), int(info[10]))
        )
    if line.find("outp_09") > -1:
        info = line.split()
        outp_9 = tuple(
            (int(info[2]), int(info[4]), int(info[6]), int(info[8]), int(info[10]))
        )
    if line.find("outp_10") > -1:
        info = line.split()
        outp_10 = tuple(
            (int(info[2]), int(info[4]), int(info[6]), int(info[8]), int(info[10]))
        )
    if line.find("outp_11") > -1:
        info = line.split()
        outp_11 = tuple(
            (int(info[2]), int(info[4]), int(info[6]), int(info[8]), int(info[10]))
        )
    if line.find("outp_12") > -1:
        info = line.split()
        outp_12 = tuple(
            (int(info[2]), int(info[4]), int(info[6]), int(info[8]), int(info[10]))
        )
    if line.find("outp_13") > -1:
        info = line.split()
        outp_13 = tuple(
            (int(info[2]), int(info[4]), int(info[6]), int(info[8]), int(info[10]))
        )
    if line.find("outp_14") > -1:
        info = line.split()
        outp_14 = tuple(
            (int(info[2]), int(info[4]), int(info[6]), int(info[8]), int(info[10]))
        )
    if line.find("outp_15") > -1:
        info = line.split()
        outp_15 = tuple(
            (int(info[2]), int(info[4]), int(info[6]), int(info[8]), int(info[10]))
        )
    if line.find("outp_16") > -1:
        info = line.split()
        outp_16 = tuple(
            (int(info[2]), int(info[4]), int(info[6]), int(info[8]), int(info[10]))
        )
    if line.find("outp_17") > -1:
        info = line.split()
        outp_17 = tuple(
            (int(info[2]), int(info[4]), int(info[6]), int(info[8]), int(info[10]))
        )
    if line.find("outp_18") > -1:
        info = line.split()
        outp_18 = tuple(
            (int(info[2]), int(info[4]), int(info[6]), int(info[8]), int(info[10]))
        )
    if line.find("outp_19") > -1:
        info = line.split()
        outp_19 = tuple(
            (int(info[2]), int(info[4]), int(info[6]), int(info[8]), int(info[10]))
        )
    if line.find("outp_20") > -1:
        info = line.split()
        outp_20 = tuple(
            (int(info[2]), int(info[4]), int(info[6]), int(info[8]), int(info[10]))
        )
    if line.find("outp_21") > -1:
        info = line.split()
        outp_21 = tuple(
            (int(info[2]), int(info[4]), int(info[6]), int(info[8]), int(info[10]))
        )
    if line.find("outp_22") > -1:
        info = line.split()
        outp_22 = tuple(
            (int(info[2]), int(info[4]), int(info[6]), int(info[8]), int(info[10]))
        )
    if line.find("outp_23") > -1:
        info = line.split()
        outp_23 = tuple(
            (int(info[2]), int(info[4]), int(info[6]), int(info[8]), int(info[10]))
        )
    if line.find("outp_24") > -1:
        info = line.split()
        outp_24 = tuple(
            (int(info[2]), int(info[4]), int(info[6]), int(info[8]), int(info[10]))
        )
    if line.find("outp_25") > -1:
        info = line.split()
        outp_25 = tuple(
            (int(info[2]), int(info[4]), int(info[6]), int(info[8]), int(info[10]))
        )
    if line.find("outp_26") > -1:
        info = line.split()
        outp_26 = tuple(
            (int(info[2]), int(info[4]), int(info[6]), int(info[8]), int(info[10]))
        )
    if line.find("outp_27") > -1:
        info = line.split()
        outp_27 = tuple(
            (int(info[2]), int(info[4]), int(info[6]), int(info[8]), int(info[10]))
        )
    if line.find("outp_28") > -1:
        info = line.split()
        outp_28 = tuple(
            (int(info[2]), int(info[4]), int(info[6]), int(info[8]), int(info[10]))
        )
    if line.find("outp_29") > -1:
        info = line.split()
        outp_29 = tuple(
            (int(info[2]), int(info[4]), int(info[6]), int(info[8]), int(info[10]))
        )
    if line.find("outp_30") > -1:
        info = line.split()
        outp_30 = tuple(
            (int(info[2]), int(info[4]), int(info[6]), int(info[8]), int(info[10]))
        )
    if line.find("outp_31") > -1:
        info = line.split()
        outp_31 = tuple(
            (int(info[2]), int(info[4]), int(info[6]), int(info[8]), int(info[10]))
        )
    if line.find("outp_32") > -1:
        info = line.split()
        outp_32 = tuple(
            (int(info[2]), int(info[4]), int(info[6]), int(info[8]), int(info[10]))
        )
    if line.find("outp_33") > -1:
        info = line.split()
        outp_33 = tuple(
            (int(info[2]), int(info[4]), int(info[6]), int(info[8]), int(info[10]))
        )
    if line.find("outp_34") > -1:
        info = line.split()
        outp_34 = tuple(
            (int(info[2]), int(info[4]), int(info[6]), int(info[8]), int(info[10]))
        )
    if line.find("outp_35") > -1:
        info = line.split()
        outp_35 = tuple(
            (int(info[2]), int(info[4]), int(info[6]), int(info[8]), int(info[10]))
        )
    if line.find("outp_36") > -1:
        info = line.split()
        outp_36 = tuple(
            (int(info[2]), int(info[4]), int(info[6]), int(info[8]), int(info[10]))
        )
    if line.find("outp_37") > -1:
        info = line.split()
        outp_37 = tuple(
            (int(info[2]), int(info[4]), int(info[6]), int(info[8]), int(info[10]))
        )
    if line.find("outp_38") > -1:
        info = line.split()
        outp_38 = tuple(
            (int(info[2]), int(info[4]), int(info[6]), int(info[8]), int(info[10]))
        )
    if line.find("outp_39") > -1:
        info = line.split()
        outp_39 = tuple(
            (int(info[2]), int(info[4]), int(info[6]), int(info[8]), int(info[10]))
        )
    if line.find("outp_40") > -1:
        info = line.split()
        outp_40 = tuple(
            (int(info[2]), int(info[4]), int(info[6]), int(info[8]), int(info[10]))
        )
    if line.find("outp_41") > -1:
        info = line.split()
        outp_41 = tuple(
            (int(info[2]), int(info[4]), int(info[6]), int(info[8]), int(info[10]))
        )
    if line.find("outp_42") > -1:
        info = line.split()
        outp_42 = tuple(
            (int(info[2]), int(info[4]), int(info[6]), int(info[8]), int(info[10]))
        )
    if line.find("outp_43") > -1:
        info = line.split()
        outp_43 = tuple(
            (int(info[2]), int(info[4]), int(info[6]), int(info[8]), int(info[10]))
        )
    if line.find("outp_44") > -1:
        info = line.split()
        outp_44 = tuple(
            (int(info[2]), int(info[4]), int(info[6]), int(info[8]), int(info[10]))
        )
    if line.find("outp_45") > -1:
        info = line.split()
        outp_45 = tuple(
            (int(info[2]), int(info[4]), int(info[6]), int(info[8]), int(info[10]))
        )
    if line.find("outp_46") > -1:
        info = line.split()
        outp_46 = tuple(
            (int(info[2]), int(info[4]), int(info[6]), int(info[8]), int(info[10]))
        )
    if line.find("outp_47") > -1:
        info = line.split()
        outp_47 = tuple(
            (int(info[2]), int(info[4]), int(info[6]), int(info[8]), int(info[10]))
        )
    if line.find("outp_48") > -1:
        info = line.split()
        outp_48 = tuple(
            (int(info[2]), int(info[4]), int(info[6]), int(info[8]), int(info[10]))
        )
output_dat = tuple(
    (
        outp_1,
        outp_2,
        outp_3,
        outp_4,
        outp_5,
        outp_6,
        outp_7,
        outp_8,
        outp_9,
        outp_10,
        outp_11,
        outp_12,
        outp_13,
        outp_14,
        outp_15,
        outp_16,
        outp_17,
        outp_18,
        outp_19,
        outp_20,
        outp_21,
        outp_22,
        outp_23,
        outp_24,
        outp_25,
        outp_26,
        outp_27,
        outp_28,
        outp_29,
        outp_30,
        outp_31,
        outp_22,
        outp_33,
        outp_34,
        outp_35,
        outp_36,
        outp_37,
        outp_38,
        outp_39,
        outp_40,
        outp_41,
        outp_42,
        outp_43,
        outp_44,
        outp_45,
        outp_46,
        outp_47,
        outp_48,
    )
)
button_dat = tuple(
    (
        btn_1,
        btn_2,
        btn_3,
        btn_4,
        btn_5,
        btn_6,
        btn_7,
        btn_8,
        btn_9,
        btn_10,
        btn_11,
        btn_12,
        btn_13,
        btn_14,
        btn_15,
        btn_16,
    )
)
parameter_dat = tuple((acd, xag, yag, po, pg))

# time.sleep(1.0)
i2c = busio.I2C(board.GP5, board.GP4)
lis3dh = adafruit_lis3dh.LIS3DH_I2C(i2c, address=0x19)
lis3dh.range = adafruit_lis3dh.RANGE_2_G
lis3dh.range = adafruit_lis3dh.RANGE_2_G
lis3dh.data_rate = adafruit_lis3dh.DATARATE_100_HZ
error_lis3dh = 0
error_flag = 0

# Define pins connected to the TLC5947
SCK = board.GP18  # SCK
MOSI = board.GP19  # MOSI
LATCH = digitalio.DigitalInOut(board.GP17)

# Initialize SPI bus.
spi = busio.SPI(clock=SCK, MOSI=MOSI)

# Initialize TLC5947
tlc5947 = adafruit_tlc5947.TLC5947(spi, LATCH)

# intialize all button status flags to 0
btp_1 = 0
btp_2 = 0
btp_3 = 0
btp_4 = 0
btp_5 = 0
btp_6 = 0
btp_7 = 0
btp_8 = 0
btp_9 = 0
btp_10 = 0
btp_11 = 0
btp_12 = 0
btp_13 = 0
btp_14 = 0
btp_15 = 0
btp_16 = 0
time_a = 0


class x_acc0:
    value = int(lis3dh.acceleration.x * parameter_dat[1])


class y_acc0:
    value = int(lis3dh.acceleration.y * parameter_dat[2])


class x_acc1:
    value = int(lis3dh.acceleration.y * parameter_dat[2])


class y_acc1:
    value = int(lis3dh.acceleration.x * parameter_dat[1])


Plunger = analogio.AnalogIn(board.A2)
keyboard = Keyboard(usb_hid.devices)
keyboard_layout = KeyboardLayoutUS(keyboard)
error_count = int(0)
button_1 = digitalio.DigitalInOut(board.GP0)
button_1.direction = digitalio.Direction.INPUT
button_1.pull = digitalio.Pull.DOWN

button_2 = digitalio.DigitalInOut(board.GP1)
button_2.direction = digitalio.Direction.INPUT
button_2.pull = digitalio.Pull.DOWN

button_3 = digitalio.DigitalInOut(board.GP2)
button_3.direction = digitalio.Direction.INPUT
button_3.pull = digitalio.Pull.DOWN

button_4 = digitalio.DigitalInOut(board.GP3)
button_4.direction = digitalio.Direction.INPUT
button_4.pull = digitalio.Pull.DOWN

button_5 = digitalio.DigitalInOut(board.GP6)
button_5.direction = digitalio.Direction.INPUT
button_5.pull = digitalio.Pull.DOWN

button_6 = digitalio.DigitalInOut(board.GP7)
button_6.direction = digitalio.Direction.INPUT
button_6.pull = digitalio.Pull.DOWN

button_7 = digitalio.DigitalInOut(board.GP8)
button_7.direction = digitalio.Direction.INPUT
button_7.pull = digitalio.Pull.DOWN

button_8 = digitalio.DigitalInOut(board.GP9)
button_8.direction = digitalio.Direction.INPUT
button_8.pull = digitalio.Pull.DOWN

button_9 = digitalio.DigitalInOut(board.GP10)
button_9.direction = digitalio.Direction.INPUT
button_9.pull = digitalio.Pull.DOWN

button_10 = digitalio.DigitalInOut(board.GP11)
button_10.direction = digitalio.Direction.INPUT
button_10.pull = digitalio.Pull.DOWN

button_11 = digitalio.DigitalInOut(board.GP12)
button_11.direction = digitalio.Direction.INPUT
button_11.pull = digitalio.Pull.DOWN

button_12 = digitalio.DigitalInOut(board.GP13)
button_12.direction = digitalio.Direction.INPUT
button_12.pull = digitalio.Pull.DOWN

button_13 = digitalio.DigitalInOut(board.GP14)
button_13.direction = digitalio.Direction.INPUT
button_13.pull = digitalio.Pull.DOWN

button_14 = digitalio.DigitalInOut(board.GP15)
button_14.direction = digitalio.Direction.INPUT
button_14.pull = digitalio.Pull.DOWN

button_15 = digitalio.DigitalInOut(board.GP20)
button_15.direction = digitalio.Direction.INPUT
button_15.pull = digitalio.Pull.DOWN

button_16 = digitalio.DigitalInOut(board.GP21)
button_16.direction = digitalio.Direction.INPUT
button_16.pull = digitalio.Pull.DOWN
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

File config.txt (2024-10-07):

acc_deadband = 1000
x_acc_gain = 3500
y_acc_gain = -3500
acc_orientation = 1
plunger_offset = 1
plunger_gain = 1
button_01 = LEFT_SHIFT
button_02 = RIGHT_SHIFT
button_03 = LEFT_CONTROL
button_04 = RIGHT_CONTROL
button_05 = ONE
button_06 = FIVE
button_07 = FOUR
button_08 = ENTER
button_09 = Q
button_10 = EQUALS
button_11 = MINUS
button_12 = F11
button_13 = T
button_14 = SPACE
button_15 = FOUR
button_16 = ENTER
outp_01 = 1011 = 10001 = 10002 = 10003 = 10004 = name
outp_02 = 0002 = 10006 = 10007 = 10008 = 10009 = name
outp_03 = 1013 = 10011 = 10012 = 10013 = 10014 = name
outp_04 = 0004 = 10000 = 10000 = 10000 = 10000 = name
outp_05 = 0005 = 10000 = 10000 = 10000 = 10000 = name
outp_06 = 0006 = 10000 = 10000 = 10000 = 10000 = name
outp_07 = 0000 = 10000 = 10000 = 10000 = 10000 = name
outp_08 = 0000 = 10000 = 10000 = 10000 = 10000 = name
outp_09 = 0000 = 10000 = 10000 = 10000 = 10000 = name
outp_10 = 0000 = 10000 = 10000 = 10000 = 10000 = name
outp_11 = 0000 = 10000 = 10000 = 10000 = 10000 = name
outp_12 = 0000 = 10000 = 10000 = 10000 = 10000 = name
outp_13 = 0000 = 10000 = 10000 = 10000 = 10000 = name
outp_14 = 0000 = 10000 = 10000 = 10000 = 10000 = name
outp_15 = 0000 = 10000 = 10000 = 10000 = 10000 = name
outp_16 = 0000 = 10000 = 10000 = 10000 = 10000 = name
outp_17 = 0000 = 10000 = 10000 = 10000 = 10000 = name
outp_18 = 0000 = 10000 = 10000 = 10000 = 10000 = name
outp_19 = 0000 = 10000 = 10000 = 10000 = 10000 = name
outp_20 = 0000 = 10000 = 10000 = 10000 = 10000 = name
outp_21 = 0000 = 10000 = 10000 = 10000 = 10000 = name
outp_22 = 0000 = 10000 = 10000 = 10000 = 10000 = name
outp_23 = 0000 = 10000 = 10000 = 10000 = 10000 = name
outp_24 = 0000 = 10000 = 10000 = 10000 = 10000 = name
outp_25 = 0000 = 10000 = 10000 = 10000 = 10000 = name
outp_26 = 0000 = 10000 = 10000 = 10000 = 10000 = name
outp_27 = 0000 = 10000 = 10000 = 10000 = 10000 = name
outp_28 = 0000 = 10000 = 10000 = 10000 = 10000 = name
outp_29 = 0000 = 10000 = 10000 = 10000 = 10000 = name
outp_30 = 0000 = 10000 = 10000 = 10000 = 10000 = name
outp_30 = 0000 = 10000 = 10000 = 10000 = 10000 = name
outp_31 = 0000 = 10000 = 10000 = 10000 = 10000 = name
outp_32 = 0000 = 10000 = 10000 = 10000 = 10000 = name
outp_33 = 0000 = 10000 = 10000 = 10000 = 10000 = name
outp_34 = 0000 = 10000 = 10000 = 10000 = 10000 = name
outp_35 = 0000 = 10000 = 10000 = 10000 = 10000 = name
outp_36 = 0000 = 10000 = 10000 = 10000 = 10000 = name
outp_37 = 0000 = 10000 = 10000 = 10000 = 10000 = name
outp_38 = 0000 = 10000 = 10000 = 10000 = 10000 = name
outp_39 = 0000 = 10000 = 10000 = 10000 = 10000 = name
outp_40 = 0000 = 10000 = 10000 = 10000 = 10000 = name
outp_41 = 0000 = 10000 = 10000 = 10000 = 10000 = name
outp_42 = 0000 = 10000 = 10000 = 10000 = 10000 = name
outp_43 = 0000 = 10000 = 10000 = 10000 = 10000 = name
outp_44 = 0000 = 10000 = 10000 = 10000 = 10000 = name
outp_45 = 0000 = 10000 = 10000 = 10000 = 10000 = name
outp_46 = 0000 = 10000 = 10000 = 10000 = 10000 = name
outp_47 = 0000 = 10000 = 10000 = 10000 = 10000 = name
outp_48 = 0000 = 10000 = 10000 = 10000 = 10000 = name

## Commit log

2024-04-25 Create README.md
    This is a simple overview of the Little Bang Board project.
2024-04-30 Add files via upload
    These are the .stl files to build the Ball shooter assembly. This design uses the typical Chinese designed shooter which is available on AliExpress.
    [shooter58.stl, shooter_retainer_rev_4.stl]
2024-10-07 This Zip Zile contains the Gerbers and drill files for fabricating a Little Bang Board
2024-10-07 Update README.md
    This is a 2nd hack for the read me. I have added a PCB and updated code that allows a config file.
2024-10-07 Add files via upload
    This file is a schematic that is applicable to the PCB files.
2024-10-07 Add files via upload
    This is an update to the shooter58. This version includes provisions for three each flat head screws to secure it to the newly designed base.
    [shooter62.stl]
2024-10-07 Add files via upload
    This is knob for the shooter project. The user will need to tap it using an M8 1.25.
    [shooter_knob_r3.stl]
2024-10-07 Add files via upload
    This is the flange for the pinball shooter. After printing it need to be reamed for an applicable hole 10mm hole for a plain bearing. For the bearing look at https://www.amazon.com/dp/B0CW345BRX/?col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
    [Shooter flange.stl]
2024-10-07 Add files via upload
    Changed the joystick button value from 0 to 2 so that it can be recognized by most game controller software packages/
2024-10-07 Add files via upload
    This is the 2.0 revision of the Bang open-source code. Stability, performance, and feature improvements are all included. This version supports a config.txt file so that no coding is required.
    [code.py]
2024-10-07 Add files via upload
    This is the new config file for the Bang 2.0 software code.
    [config.txt]
2024-10-07 Add files via upload
    This is the 2.0 version for the Little Bang Board Instructions.
2024-10-07 Add files via upload
    This is the 2.0 version of the Little Bang Board Project Instruction.
2024-11-04 Add files via upload
    This is an image of all the source code. Once the Pico has been initialized with the adafruit circuitpython kernel, place the content of this zipped file into the root of the pico. Make sure it over-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
2024-11-04 Add files via upload
    This is the first file that needs to be placed into the root folder of the pico. Once placed into the folder, the pico should reboot.
2024-11-04 Update README.md
    added instructions for manually loading an existing RP Pico
2025-11-13 Update README.md
    Added announcement of MJR's Pinscape Pico support for this project.
2025-11-13 Add files via upload
    This JSON file is a configuration script for the Little Bang Board project. Please refer to MJR's GitHub page for details: https://github.com/mjrgh/PinscapePico
2025-11-14 Update README.md
    Added description for the new version 2 of the Little Bang Board.
2025-11-14 Add files via upload
    Added fabrication files for the Rev 2 Little Bang Board. Also added KiCAD 8 project source files.
